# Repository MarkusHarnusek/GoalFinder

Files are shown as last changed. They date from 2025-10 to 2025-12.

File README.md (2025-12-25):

# Goalfinder

## Project structure

    .
    ├── github              GitHub workflows for CI/CD
    ├── .vscode             Configuration files for Visual Studio Code
    ├── assets              Assets for development and documentation
    ├── blueprint           Hardware design files, including 3D models and PCB layouts
    ├── client              Software for the Goalfinder Board, including firmware
    ├── doc-alt             Documentation from the previous repository
    ├── web                 Development directory for the web-based access point
    ├── .gitignore          Files and directories excluded from git source control
    ├── LICENSE             Licensing information for the project
    ├── package-lock.json   Locked npm dependencies for consistent builds
    └── README.md           Description of the repository

## Credits

This project was conceived and envisioned by the [previous team](https://github.com/htl-leo-club-embedded-iot/GoalFinder)

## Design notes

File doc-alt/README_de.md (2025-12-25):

# Goal Finder

IoT project in scope of POSE-PRPR and WLC, HTL Leonding, 2BHIF, JG 2324 in cooperation with Universität Wien.

[Erste Schritte](docs/gettting_started_de.md)

## Introduction

When visually impaired people play basket ball, they need acoustic assistance for locating the basket and as feedback if the basket is hit.

For locating the basket, a constant beeping is sufficient. For a hit, a triumph fanfare may be played. Miss detection may result in an according tune.

Basketball

Such assistance device may be directly mounted on the basket rack. They shall be easily mountable, e.g. by sliding them on the board or basket.

For hit detection, a short range laser distance sensor (ToF - time of flight sensor) is used. It is looking through the mesh of the basket and is therefore capable detecting a ball falling through the basket.

Sensor Sketch

Optionally, hitting the basket-board may be detected using an acceleration sensor. When a ball hits the board or the ring, heavy motion can be expected and detected. If the ball does not pass the basket in time, a miss is detected.

The sensor device shall be controlled via a web application designed for mobile devices, to operate the system on the (basketball) field. The application may also assist in the game, for instance by automatically counting hits for multiple players.

## Project Goals

A basketball assistance device as described about shall be developed and deployed in the field.

## Hardware Platform

+ SoC: ESP32, see [Random Nerd Tutorials: ESP32- Pinout](https://randomnerdtutorials.com/esp32-pinout-reference-gpios/)
+ Distance Sensor: ToF sensor connected via I²C, such as VL53L0X. see [YouTube: ToF used with ESP32](https://www.youtube.com/watch?v=HeMlcCDYCEk).
+ Option: Acceleration sensor (TBD).
+ Audio: ESP32 DAC with external pre-amplifier, see [YouTube: ESP32 Audio: I2S & Built-In DACs Explained](https://www.youtube.com/watch?v=lgDu88Y411o)
+ Power supply: Grid via power adapter or power bank.

## Use Cases and User Stories

1. As a user, I want to control the device via web application on a smart phone as well as on a desktop PC.
1. As a player, I want the device to provide acoustic hints of the basket location.
1. As a player, I want the device to sound a triumph tune when the ball hits the basket.
1. As a player, it would be great to hear a sound when the ball hits the basket rack but not the basket.
1. As a user, I want to connect to the device via WiFi network that is spread by the device.
1. As a user, I want to integrate the device into my WiFi network easily.
1. As a user, I want that the device time is synchronized with the real time of my timezone.
1. As a user, I want to update the device software over the air.

## Tasks

This section describes the first task to be tackled on a high-level base.

1. Specify a roadmap / time table for the given tasks and user story implementation.
1. Develop a software design showing the major software components and their relations as well as required communication protocols.
1. Integrate a WiFi setup and configuration on the device.
1. Integrate a web server on the device.
1. Integrate an SNTP client on the device, including SNTP configuration via integrated web server.
1. Implement the SW-component to measure distances via distance senor.
1. Option: Implement SW-component to measure motion via motion sensor.
1. Implement hit / miss detection based on the measured values.
1. Implement audio output
1. Integrate suitable audio tracks for signalling events.
1. Option: Implement audio feedback via Bluetooth.
1. Implement a web front-end suitable for configuring the sensor device
1. Implement a web front-end for game play.
1. Integrate and enable SWUOTA (software update over the air).

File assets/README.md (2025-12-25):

# Structure
    .
    ├── audio               Audio files
    |   ├── beep                Beep Sounds
    |   ├── goal                Goal sounds
    |   ├── metronome           Metronome Sounds
    |   ├── miss                Miss sounds
    |   └── success             Success sounds
    └── img                 Image files
        └── logo                Logos

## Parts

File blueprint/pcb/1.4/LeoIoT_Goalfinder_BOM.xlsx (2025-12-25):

Reference | Value | Footprint | Qty | Beschreibung | Comment / Supplier
C1 | 22µF | Capacitor_THT:CP_Radial_D5.0mm_P2.00mm | 1 | Polarized capacitor, small symbol
C2 | 4,7µF | Capacitor_THT:CP_Radial_D5.0mm_P2.00mm | 1 | Unpolarized capacitor, small symbol
C3 | 0,1µF | Capacitor_THT:C_Rect_L13.0mm_W4.0mm_P10.00mm_FKS3_FKP3_MKS4 | 1 | Unpolarized capacitor, small symbol
C4,C5,C6,C7,C8 | 100nF | Capacitor_SMD:C_0805_2012Metric_Pad1.18x1.45mm_HandSolder | 5 | Unpolarized capacitor, small symbol
Copt4,Copt5,Copt6,Copt7,Copt8 | 100nF | Capacitor_THT:C_Disc_D5.0mm_W2.5mm_P2.50mm | 0 | Unpolarized capacitor, small symbol | Optional for THT parts, replaces C4, C5, C6, C7, C8 https://www.reichelt.de/de/de/shop/produkt/keramik-kondensator_100_nf_-20_80_y5v_50_100_v_rm_5-9265
J2 | LED Strip | Connector_JST_2.54:JST_XH_B2B-XH-A_1x02_P2.54mm_Vertical | 1 | Connector for LED Strip
J1 | USB_B_Micro_Breakout | Breakout_Boards:Micro-USB_BreakoutBoard | 1 | USB Micro Type B connector | https://www.amazon.de/KARELLS-Steckerkabel-Verl%C3%A4ngerungskabel-Stromladekabel-Ersatzkabel/dp/B0D6362W88
D1, J1e1 | Conn_01x02_Pin | 5V LED Strip, max 30W | 1 | LED Strip with connector suitable for J2 | https://www.amazon.de/GOMING-COB-Selbstklebend-Wasserdicht-Lichtband/dp/B09VGR6PWH/ref=sr_1_4?th=1
J3 | GAIN | Connector_PinHeader_2.54mm:PinHeader_2x05_P2.54mm_Vertical | 1 | Jumper bar for gain selection | either wire bridge or:
 |  |  |  |  | Jumper: https://www.reichelt.de/de/de/shop/produkt/kurzschlussbruecke_schw_m_grifflasche-9019
 |  |  |  |  | Pin Header: https://www.reichelt.de/de/de/shop/produkt/stiftleiste_2x20-pol_vergoldet_2_54mm-235664
LS1 | Speaker | Breakout_Boards:Mono-Enclosed_Speaker_70x30x17mm_onboard | 1 | Speaker, 3 W, 8 Ohm | https://www.amazon.de/dp/B09PL6XFHC
Q1 | IRFZ44N | Package_TO_SOT_THT:TO-220-3_Horizontal_TabDown | 1 | FET | https://www.reichelt.de/de/de/shop/produkt/mosfet_n-ch_60v_48a_110w_0_023r_to220ab-257487
R1,R2 | 100k | Resistor_THT:R_Axial_DIN0309_L9.0mm_D3.2mm_P12.70mm_Horizontal | 2 | Resistor
R4 | 1k | Resistor_THT:R_Axial_DIN0309_L9.0mm_D3.2mm_P12.70mm_Horizontal | 1 | Resistor
R5 | 33k | Resistor_THT:R_Axial_DIN0309_L9.0mm_D3.2mm_P12.70mm_Horizontal | 1 | Resistor
U1 | ESP32_D1_mini | ESP32_D1_mini:ESP32_D1_mini | 1 | ESP32 D1 mini from AZ-Delivery | https://www.amazon.de/AZDelivery-Bluetooth-Internet-Entwicklungsboard-kompatibel/dp/B08BTYCGVV
U2 | VL53L0X_Breakout | Breakout_Boards:VL53L0X_Breakout_Board_vertical_flat | 1 | 2m distance ranging ToF sensor, Optical LGA12 | https://www.amazon.de/AZDelivery-VL53L0X-Flight-kompatibel-Arduino/dp/B086TSNTFD
U3 | MAX98357A_Breakout | Breakout_Boards:MAX98357A_Breakout_Board | 1 | Mono DAC with amplifier, I2S, PCM, TDM, 32-bit, 96khz, 3.2W, TQFP-16 | https://www.amazon.de/AZDelivery-filterloses-Breakout-Modul-Decoder-Modul-Anwendungsbereich/dp/B09PL947ZG
U4 | SW420_Breakout | Breakout_Boards:SW420_Breakout_Board_Horizontal | 1 | Vibrationsensor, Shocksensor | https://www.amazon.de/AZDelivery-Vibration-Sch%C3%BCttel-Ersch%C3%BCtterung-Arduino/dp/B07V9CZ89G

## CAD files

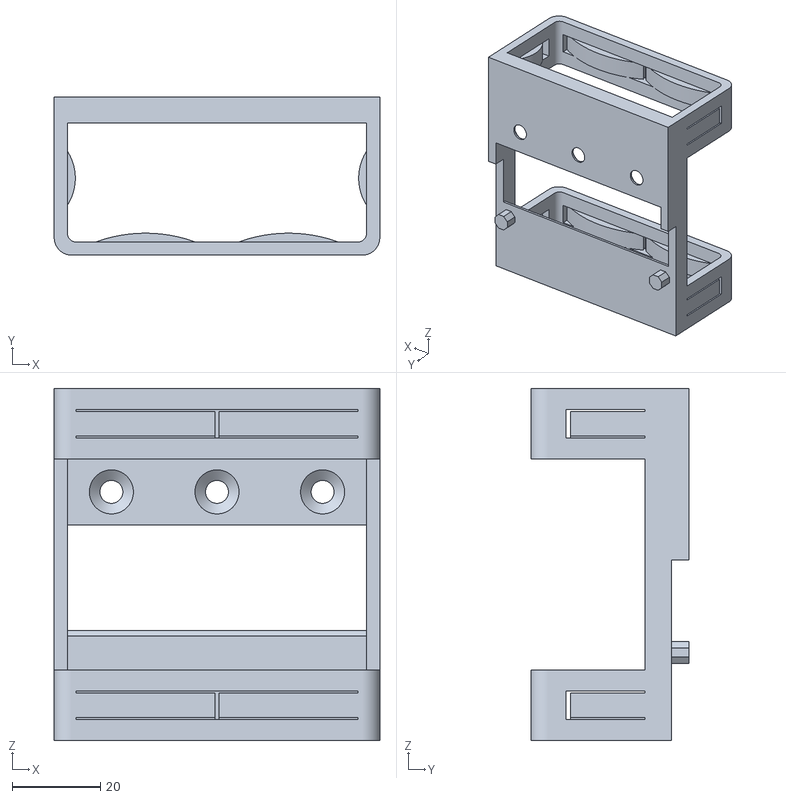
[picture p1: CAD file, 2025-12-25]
blueprint/3d-print/latest-export/powerbank-bracket.stl
74.0 x 36.0 x 80.0

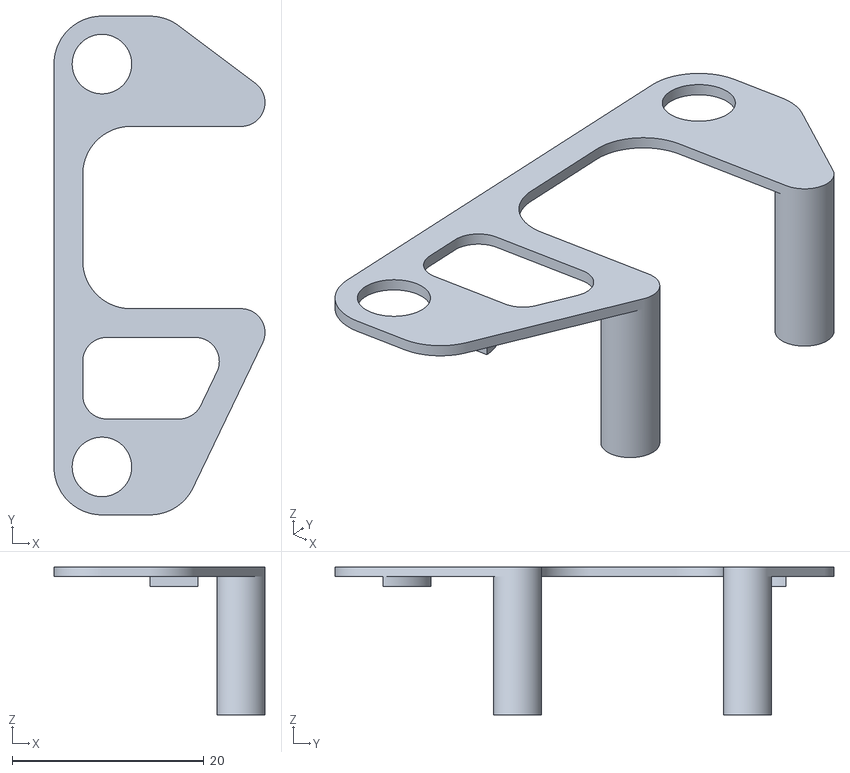
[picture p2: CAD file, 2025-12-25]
blueprint/3d-print/latest-export/bracket-top-left.stl
22.0 x 52.0 x 15.4

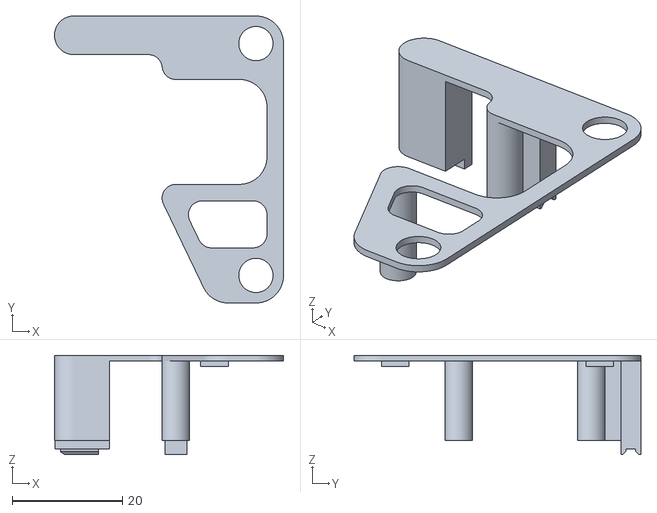
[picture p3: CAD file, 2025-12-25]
blueprint/3d-print/latest-export/bracket-top-right.stl
41.5 x 52.0 x 18.0

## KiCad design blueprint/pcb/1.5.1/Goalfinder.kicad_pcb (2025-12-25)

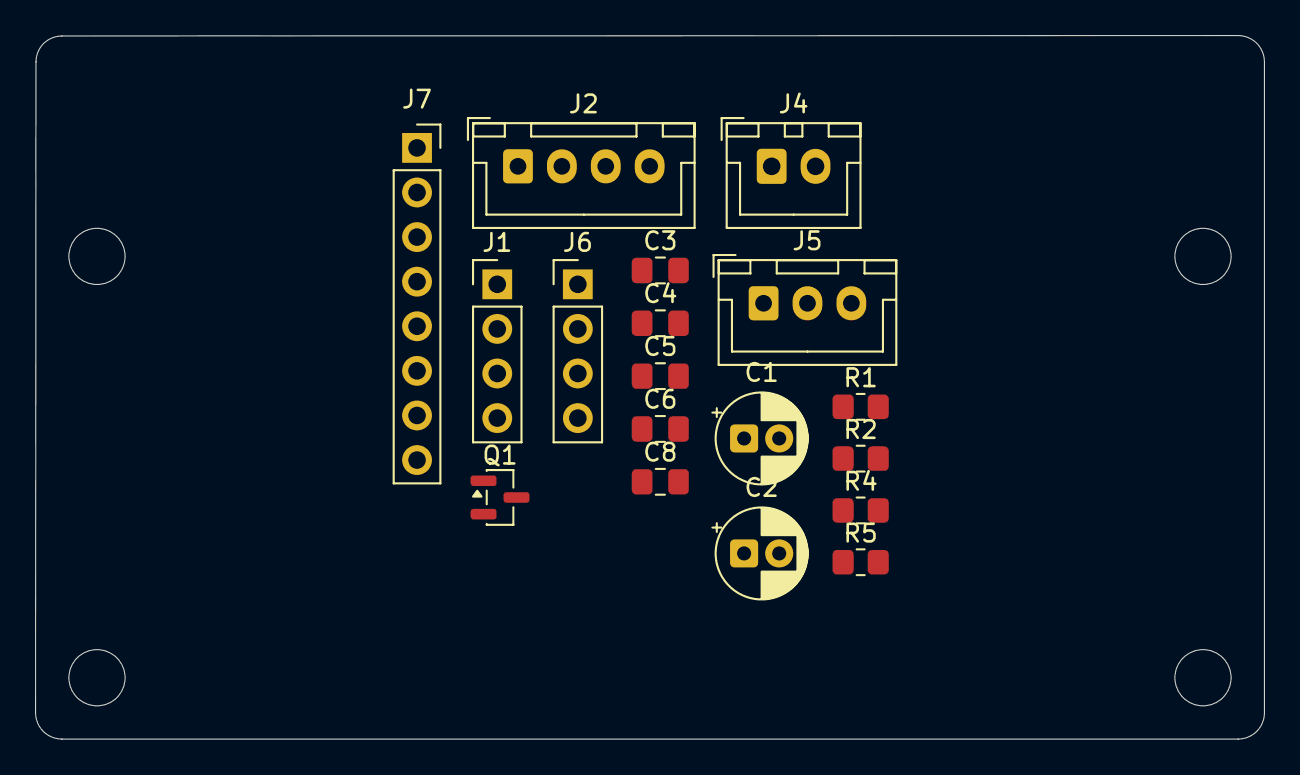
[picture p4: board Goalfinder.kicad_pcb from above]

Board: 2 copper layers, 70.0 x 40.1 mm, 22 parts (0 on the bottom side), 7 nets, no tracks yet.

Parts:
C1: 22µF; CP_Radial_D5.0mm_P2.00mm
C2: 4,7µF; CP_Radial_D5.0mm_P2.00mm
C3, C4, C5, C6, C8: 100nF; C_0805_2012Metric_Pad1.18x1.45mm_HandSolder
J1: USB in; PinHeader_1x04_P2.54mm_Vertical
J2: USB-ESP; JST_XH_B4B-XH-A_1x04_P2.50mm_Vertical
J4: LED Strip; JST_XH_B2B-XH-A_1x02_P2.50mm_Vertical
J5: SW240 - Vcc/D0/GND; JST_XH_B3B-XH-A_1x03_P2.50mm_Vertical
J6: VL53L0X-ToF Vcc/SDA/SCL/GND; PinHeader_1x04_P2.54mm_Vertical
J7: Conn_01x08_Pin; PinSocket_1x08_P2.54mm_Vertical
MH1, MH2, MH3, MH4: MountingHole_3.2mm_M3
Q1: IRLML2502; SOT-23
R1, R2: 100k; R_0805_2012Metric_Pad1.20x1.40mm_HandSolder
R4: 1k; R_0805_2012Metric_Pad1.20x1.40mm_HandSolder
R5: 33k; R_0805_2012Metric_Pad1.20x1.40mm_HandSolder

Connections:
3V3: C5.1, C6.1, C8.1, J5.1, J6.1, J7.1
5V: C1.1, C2.1, C3.1, C4.1, J1.1, J2.1, J4.1, R1.1
/LED_PWR: J4.2, Q1.3 (D)
GND: C1.2, C2.2, C3.2, C4.2, C5.2, C6.2, C8.2, J1.4, J2.4, J5.3, J6.4, J7.2, Q1.2 (S), R2.1, R5.2
unnamed: J1.2, J2.2
unnamed: J1.3, J2.3
unnamed: Q1.1 (G), R4.2, R5.1

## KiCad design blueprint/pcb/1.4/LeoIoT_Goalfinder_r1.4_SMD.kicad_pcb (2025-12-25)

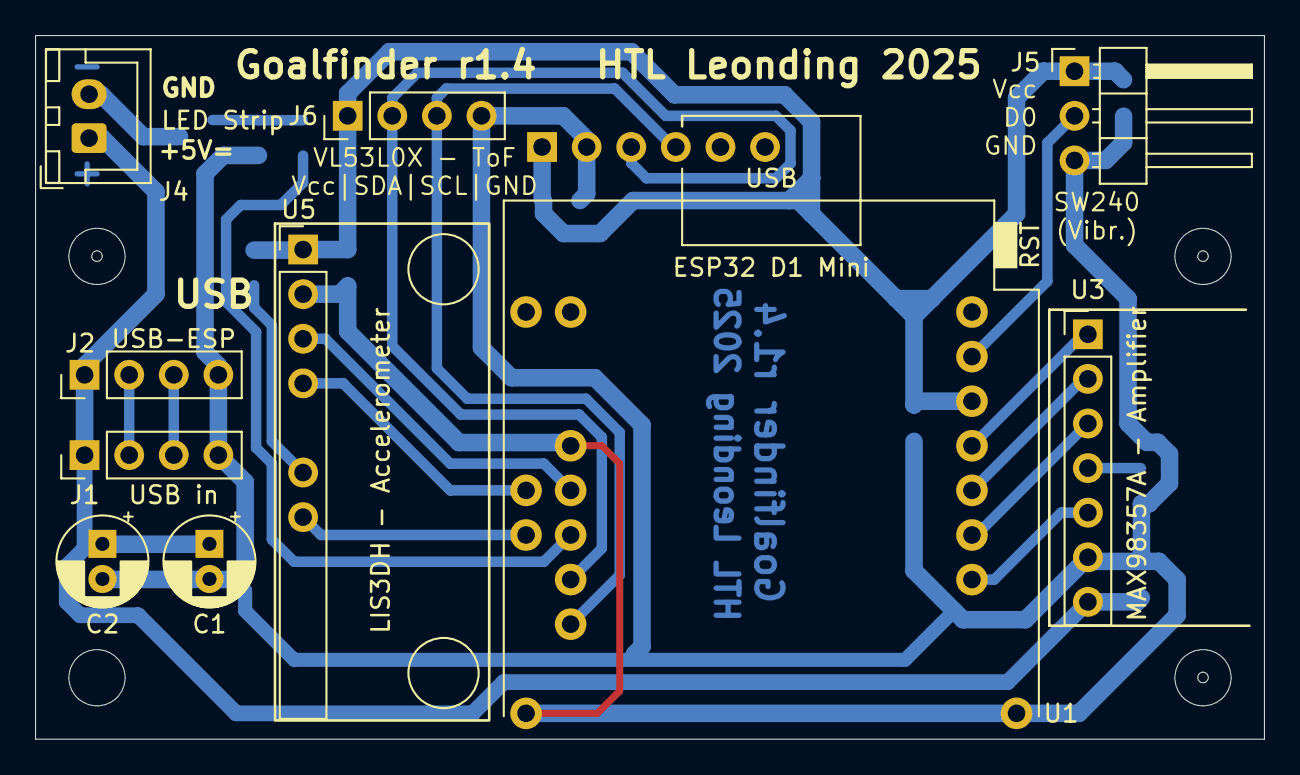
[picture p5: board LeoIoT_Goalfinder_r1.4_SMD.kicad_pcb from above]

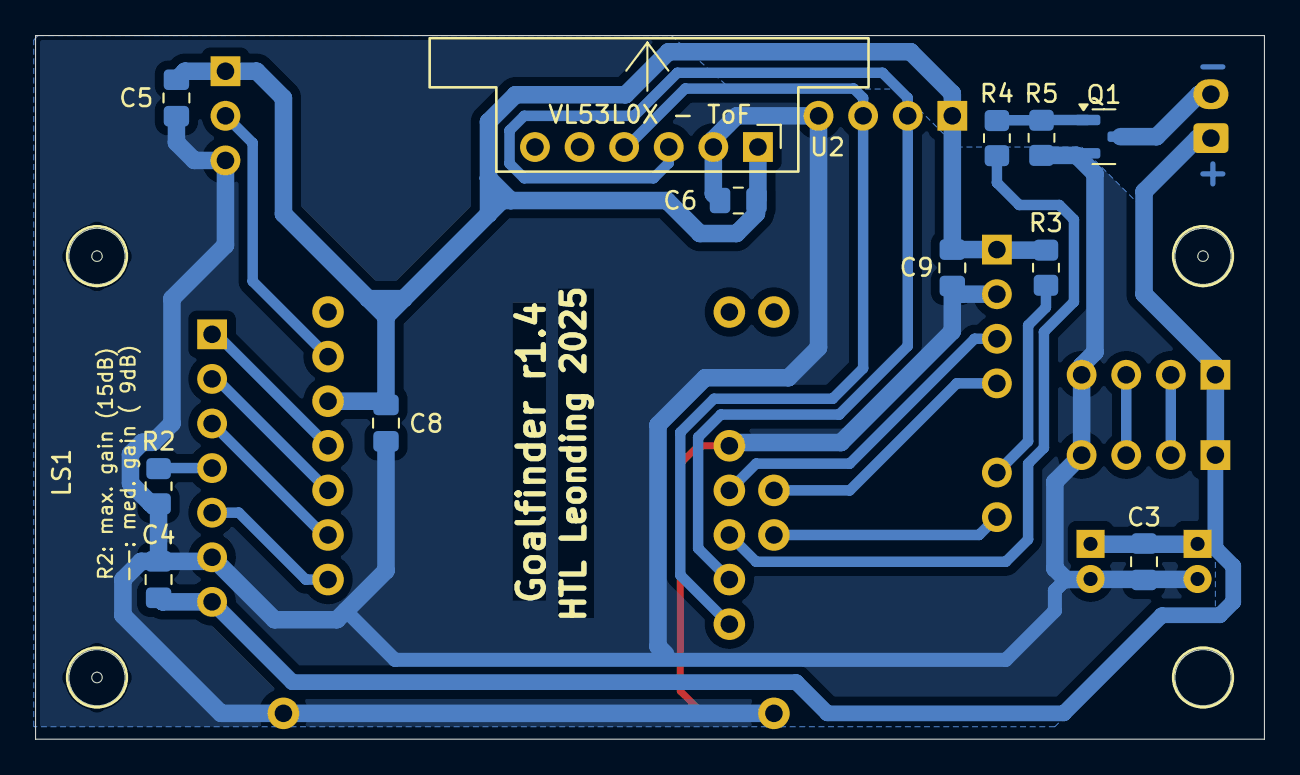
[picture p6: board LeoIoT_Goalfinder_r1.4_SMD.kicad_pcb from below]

Board: 2 copper layers, 70.0 x 40.1 mm, 27 parts (13 on the bottom side), 20 nets.

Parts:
C1: 22µF; CP_Radial_D5.0mm_P2.00mm
C2: 4,7µF; CP_Radial_D5.0mm_P2.00mm
C3, C4, C5, C6, C8, C9: 100nF; C_0805_2012Metric_Pad1.18x1.45mm_HandSolder
J1: USB in; PinHeader_1x04_P2.54mm_Vertical
J2: USB-ESP; PinHeader_1x04_P2.54mm_Vertical
J4: LED Strip; JST_XH_B2B-XH-A_1x02_P2.50mm_Vertical
J5: SW240 - Vcc/D0/GND; PinHeader_1x03_P2.54mm_Horizontal
J6: VL53L0X-ToF Vcc/SDA/SCL/GND; PinHeader_1x04_P2.54mm_Vertical
LS1: Speaker; Mono-Enclosed_Speaker_70x30x17mm_onboard
MH1, MH2, MH3, MH4: MountingHole_3.2mm_M3
Q1: IRLML2502; SOT-23
R2, R3: 100k; R_0805_2012Metric_Pad1.20x1.40mm_HandSolder
R4: 1k; R_0805_2012Metric_Pad1.20x1.40mm_HandSolder
R5: 33k; R_0805_2012Metric_Pad1.20x1.40mm_HandSolder
U1: ESP32 D1 Mini; ESP32_D1_mini
U2: VL53L0X - ToF; VL53L0X_Breakout_Board_vertical_flat
U3: MAX98357A - Amplifier; MAX98357A_Breakout_Board
U5: LIS3DH - Accelerometer; LIS3DH_Breakout_Board

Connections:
3V3: C5.1, C6.1, C8.1, C9.1, J5.1, J6.1, R3.1, U1.16 (3V3), U2.1 (VCC), U5.1 (VCC)
5V: C1.1, C2.1, C3.1, C4.1, J1.1, J2.1, J4.1, U3.7 (VDD)
/LED_PWR: J4.2, Q1.3 (D)
GND: C1.2, C2.2, C3.2, C4.2, C5.2, C6.2, C8.2, C9.2, J1.4, J2.4, J5.3, J6.4, Q1.2 (S), R2.1, R5.2, U1.1 (GND), U1.22 (GND), U1.33 (GND), U2.2 (GND), U3.6 (GND), U5.2 (GND)
unnamed: J1.2, J2.2
unnamed: J1.3, J2.3
unnamed: J5.2, U1.18 (IO_13/TCK)
unnamed: J6.2, U1.27 (IO_21/SDA_1), U2.3 (SDA)
unnamed: J6.3, U1.25 (IO_22/SCL_1), U2.4 (SCL)
unnamed: U1.31 (IO_16/U2_RX), U5.3 (SCL/SPC)
unnamed: U1.32 (IO_04), U5.4 (SDA/SDI/SDO)
unnamed: R3.2, U5.6 (CS)
unnamed: U1.30 (IO_12/TDI), U5.7 (INT1)
unnamed: Q1.1 (G), R4.2, R5.1
unnamed: U1.14 (IO_05/SS), U3.1 (LRCLK)
unnamed: R4.1, U1.29 (IO_17/U2_TXC)
unnamed: U1.8 (IO_18/CLK), U3.5 (~SD_MODE)
unnamed: U1.10 (IO_19/MISO), U3.3 (DIN)
unnamed: U1.12 (IO_23/MOSI), U3.2 (BCLK)
unnamed: R2.2, U3.4 (GAIN_SLOT)

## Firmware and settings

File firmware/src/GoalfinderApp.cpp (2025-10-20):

#include <GoalfinderApp.h>
#include <HardwareSerial.h>
#include <Settings.h>

// === Hardware-Pins und Konstanten ===
const int GoalfinderApp::pinTofSda = 22;
const int GoalfinderApp::pinTofScl = 21;
const int GoalfinderApp::pinI2sBclk = 23;
const int GoalfinderApp::pinI2sWclk = 5;
const int GoalfinderApp::pinI2sDataOut = 19;
const int GoalfinderApp::pinLedPwm = 17;
const int GoalfinderApp::pinRandomSeed = 36;

const int GoalfinderApp::ledPwmChannel = 0;

const int GoalfinderApp::ballHitDetectionDistance = 180;
const int GoalfinderApp::shotVibrationThreshold = 2000;
const int GoalfinderApp::maxShotDurationMs = 5000;

const char* GoalfinderApp::waitingClip = "/waiting.mp3";

const char* GoalfinderApp::hitClips[] = { "/hit-1.mp3" };
const int   GoalfinderApp::hitClipsCnt = sizeof(GoalfinderApp::hitClips) / sizeof(GoalfinderApp::hitClips[0]);

const char* GoalfinderApp::tickClips[] = { "/tick-1.mp3" };
const int   GoalfinderApp::tickClipsCnt = sizeof(GoalfinderApp::tickClips) / sizeof(GoalfinderApp::tickClips[0]);

const char* GoalfinderApp::missClips[] = { "/miss-1.mp3" };
const int   GoalfinderApp::missClipsCnt = sizeof(GoalfinderApp::missClips) / sizeof(GoalfinderApp::missClips[0]);

// === FreeRTOS Handles ===
TaskHandle_t GoalfinderApp::TaskAudio = nullptr;
TaskHandle_t GoalfinderApp::TaskDetection = nullptr;
TaskHandle_t GoalfinderApp::TaskLed = nullptr;
SemaphoreHandle_t GoalfinderApp::xMutex = nullptr;

// === Konstruktor / Destruktor ===
GoalfinderApp::GoalfinderApp() :
    Singleton<GoalfinderApp>(),
    fileSystem(true),
    webServer(&fileSystem),
    sntp(),
    audioPlayer(&fileSystem, pinI2sBclk, pinI2sWclk, pinI2sDataOut),
    tofSensor(),
    vibrationSensor(),
    ledController(pinLedPwm, ledPwmChannel),
    announcing(false),
    metronomeIntervalMs(2000),
    lastMetronomeTickTime(0),
    announcement(Announcement::None),
    lastShockTime(0),
    isSoundEnabled(true)
{}

GoalfinderApp::~GoalfinderApp() {}

// === Getter / Setter ===
void GoalfinderApp::SetIsSoundEnabled(bool value) {
    isSoundEnabled = value;
}

bool GoalfinderApp::IsSoundEnabled() {
    return isSoundEnabled;
}

// === Initialisierung ===
void GoalfinderApp::Init() {
    delay(100);
    Serial.begin(115200);
    randomSeed(analogRead(pinRandomSeed));

    if (!fileSystem.Begin()) {
        Serial.println("FS initialization failed");
        return;
    }

    Settings* settings = Settings::GetInstance();
    String ssid = settings->GetDeviceName();
    String wifiPw = settings->GetDevicePassword();

    WiFi.mode(WIFI_AP);
    WiFi.softAP(ssid, wifiPw);
    WiFi.setSleep(false);
    Serial.println(WiFi.softAPIP());

    webServer.Begin();
    sntp.Init();
    vibrationSensor.Init();
    tofSensor.Init(pinTofScl, pinTofSda);
    ledController.SetMode(LedMode::Flash);

    UpdateSettings(true);

    xMutex = xSemaphoreCreateMutex();

    xTaskCreatePinnedToCore(TaskAudioCode, "TaskAudio", 8192, this, 1, &TaskAudio, 1);
    xTaskCreatePinnedToCore(TaskDetectionCode, "TaskDetection", 8192, this, 2, &TaskDetection, 1);
    xTaskCreatePinnedToCore(TaskLedCode, "TaskLed", 8192, this, 1, &TaskLed, 0);

    Serial.println("All tasks started.");
}

void GoalfinderApp::UpdateSettings(bool force) {
    Settings* settings = Settings::GetInstance();
    if (force || settings->IsModified()) {
        audioPlayer.SetVolume(settings->GetVolume());
        ledController.SetMode(settings->GetLedMode());
        vibrationSensor.SetSensitivity(settings->GetVibrationSensorSensitivity());
    }
}

// === Tasks ===
void GoalfinderApp::TaskAudioCode(void *pvParameters) {
    GoalfinderApp* app = (GoalfinderApp*)pvParameters;
    for (;;) {
        if (app->IsSoundEnabled()) {
            app->audioPlayer.Loop();
            if (!app->audioPlayer.IsPlaying()) {
                app->TickMetronome();
            }
        }
        vTaskDelay(1 / portTICK_PERIOD_MS);
    }
}

void GoalfinderApp::TaskDetectionCode(void *pvParameters) {
    GoalfinderApp* app = (GoalfinderApp*)pvParameters;
    for (;;) {
        app->UpdateSettings();
        app->DetectShot();
        app->ProcessAnnouncement();
        vTaskDelay(1 / portTICK_PERIOD_MS);
    }
}

void GoalfinderApp::TaskLedCode(void *pvParameters) {
    GoalfinderApp* app = (GoalfinderApp*)pvParameters;
    for (;;) {
        app->ledController.Loop();
        vTaskDelay(1 / portTICK_PERIOD_MS);
    }
}

// === Hauptlogik ===
void GoalfinderApp::TickMetronome() {
    unsigned long currentTime = millis();
    if ((currentTime - lastMetronomeTickTime) > metronomeIntervalMs) {
        lastMetronomeTickTime = currentTime;
        const char* clipName = (lastShockTime > 0) ? waitingClip : tickClips[0];
        PlaySound(clipName);
    }
}

void GoalfinderApp::DetectShot() {
    if (lastShockTime == 0) {
        if (!(announcing && audioPlayer.IsPlaying())) {
            announcing = false;
            long vibration = vibrationSensor.Vibration(10000);
            if (vibration > shotVibrationThreshold) {
                lastShockTime = millis();
                Serial.printf("%4.3f: shot detected\n", millis() / 1000.0);
            }
        }
    }

    unsigned long currentTime = millis();
    if (lastShockTime > 0 && (currentTime - lastShockTime) < maxShotDurationMs) {
        int distance = tofSensor.ReadSingleMillimeters();
        if (distance > 20 && distance < ballHitDetectionDistance) {
            AnnounceHit();
            lastShockTime = 0;
        }
    }
    if (lastShockTime > 0 && (currentTime - lastShockTime) > maxShotDurationMs) {
        AnnounceMiss();
        lastShockTime = 0;
    }
}

void GoalfinderApp::ProcessAnnouncement() {
    switch (announcement) {
        case Announcement::Shot:
            AnnounceEvent("-> shot", nullptr);
            break;
        case Announcement::Hit:
            AnnounceEvent("-> hit", hitClips[0]);
            break;
        case Announcement::Miss:
            AnnounceEvent("-> miss", missClips[0]);
            break;
        default:
            break;
    }
    announcement = Announcement::None;
}

// === Neue fehlende Implementierungen ===
void GoalfinderApp::AnnounceHit() {
    detectedHits++;
    announcement = Announcement::Hit;
    Serial.printf("%4.3f: Hit detected! Total hits: %d\n", millis() / 1000.0, detectedHits);
}

void GoalfinderApp::AnnounceMiss() {
    detectedMisses++;
    announcement = Announcement::Miss;
    Serial.printf("%4.3f: Miss detected! Total misses: %d\n", millis() / 1000.0, detectedMisses);
}

void GoalfinderApp::AnnounceEvent(const char* traceMsg, const char* sound) {
    Serial.printf("%4.3f: announcing event '%s'\n", millis() / 1000.0, traceMsg);
    if (sound) {
        announcing = true;
        PlaySound(sound);
    }
}

void GoalfinderApp::PlaySound(const char* soundFileName) {
    if (soundFileName) {
        Serial.printf("%4.3f: starting playback of: '%s'\n", millis() / 1000.0, soundFileName);
        audioPlayer.PlayMP3(soundFileName);
    }
}
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

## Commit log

2025-10-20 added multi-threading
2025-12-24 Changed .gitignore
    [Pin_Configuration.fzz]
2025-12-25 Structured housing
    [JST-SYP_Female.step, JST-SYP_Male.step, LeoIoT-Goalfinder-Assembly_GF1_4_compact.FCStd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]
2025-12-25 Versioned blueprint/ subdirectories
    [LeoIoT_Goalfinder-B_Cu.gbr, LeoIoT_Goalfinder-B_Mask.gbr, LeoIoT_Goalfinder-B_Paste.gbr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]
2025-12-25 Restrucured blueprints/
    [bracket-top-left.stl, bracket-top-right.stl, powerbank-bracket.stl]
2025-12-25 Sorted housing
2025-12-25 Revised PCB into new 1.5 version
    [Goalfinder.kicad_pcb, Goalfinder.kicad_sch, LeoIoT_Goalfinder.kicad_pcb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]
2025-12-25 Copied into new 1.5.1 PCB directory
    [Goalfinder.kicad_pcb, Goalfinder.kicad_sch]
2025-12-25 Reworked Schematic to use MPU6050
    [Goalfinder.kicad_pcb, Goalfinder.kicad_sch]
2025-12-25 Cleared PCB
    [Goalfinder.kicad_pcb, Goalfinder.kicad_sch]
